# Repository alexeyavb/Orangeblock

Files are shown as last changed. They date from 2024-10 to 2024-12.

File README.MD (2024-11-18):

*Why is need:*

* WeAct studio Black pill stm32f411ceu6
* Any working pcm5102 shield configured as slave in i2s Phillips standard
* Any working pcm1808 shield configured as slave in i2s Phillips standard

**Big Steps for implementing**
+ make test board
+ write firmware fo stm32
+ write in/out audio  overlay for linux dts tree
+ write linux device driver for orange pi

**Wh implemented as demo**
+ simple i2s-i2s bridge firmware for stm32 (in+out) in 48k 24bit 256fs
+ opi worked as i2s master
+ stm32<->opi-mcu bridge as slave with internal clocking
+ stm32 i2s master reciever with internal clock and mclock/bclock output
+ stm32 i2s master transmitter with internal clock and mclock/bclock utput
+ clock dividers for 48/96/192K audio processing and internal i2s pll reconf +- 0.04% clock error

- simple stm32-i2s kernel audio device driver for use ALSA/JACKd (audio in and audio out)
- simple overlay for enabling i2s in Orange PI PC/ONE in 40pin GPIO header. Implement as 48k 24bit 256fs only without bclck change

* **20241031** Complete tracing shield
* **20241107** received factory printed boards

2024/Nov/08
* Received printed PCB
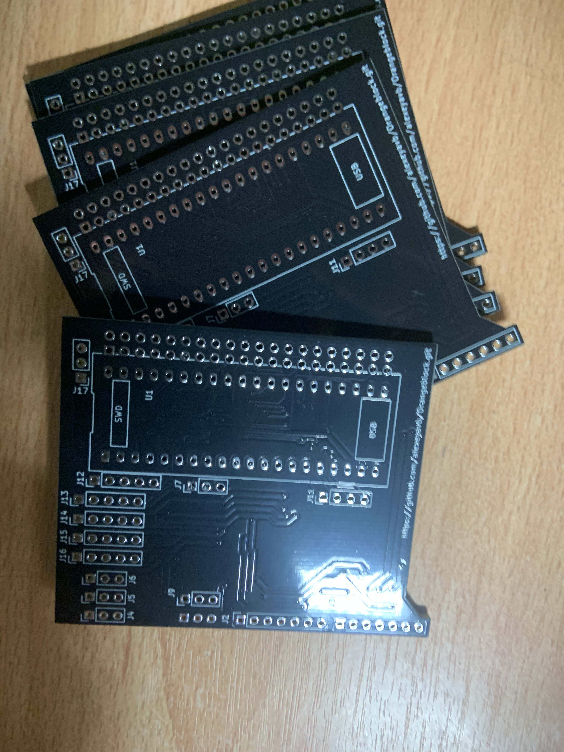
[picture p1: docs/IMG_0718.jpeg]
Printed PCB1

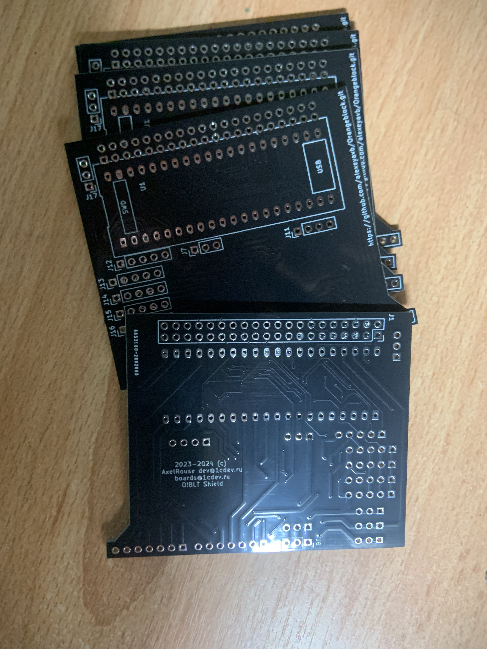
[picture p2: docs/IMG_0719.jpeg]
Printed PCB2

2024/Nov/09
* Soldered sockets anmd pins
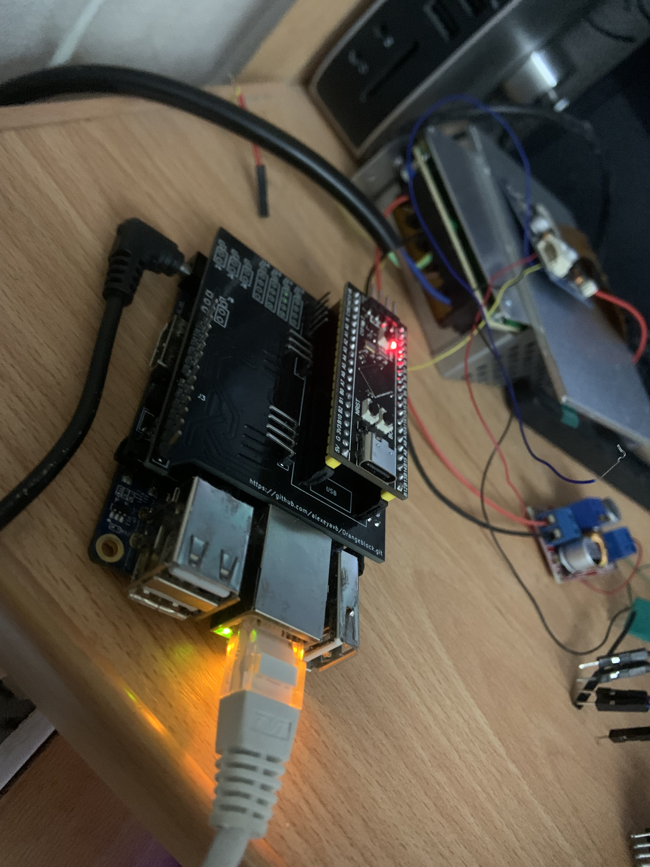
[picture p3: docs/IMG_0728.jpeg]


+ ***Process Testing with STM32 board***
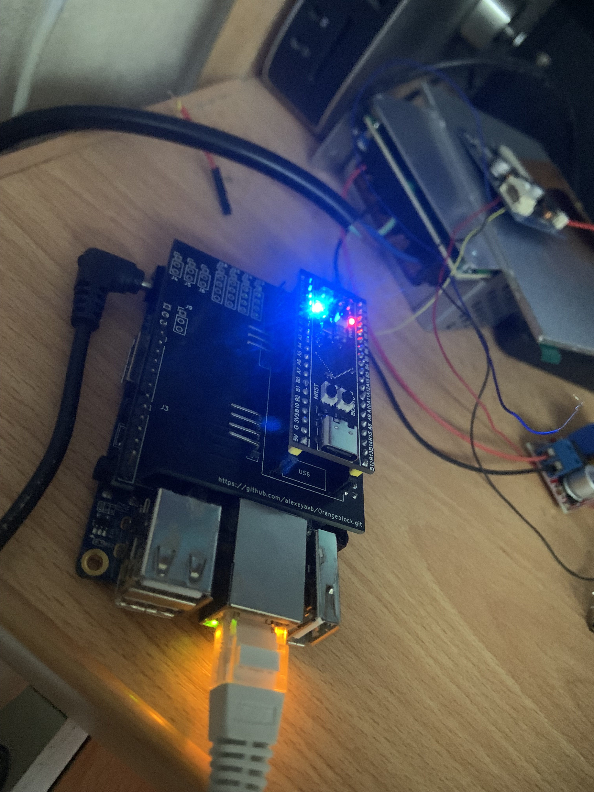
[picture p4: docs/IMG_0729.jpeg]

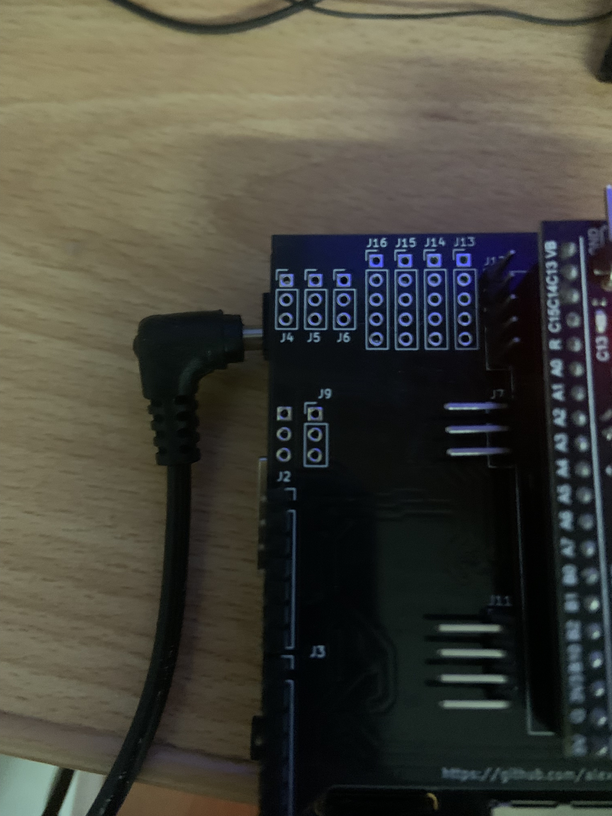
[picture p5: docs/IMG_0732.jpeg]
testing record without ADC PCB1

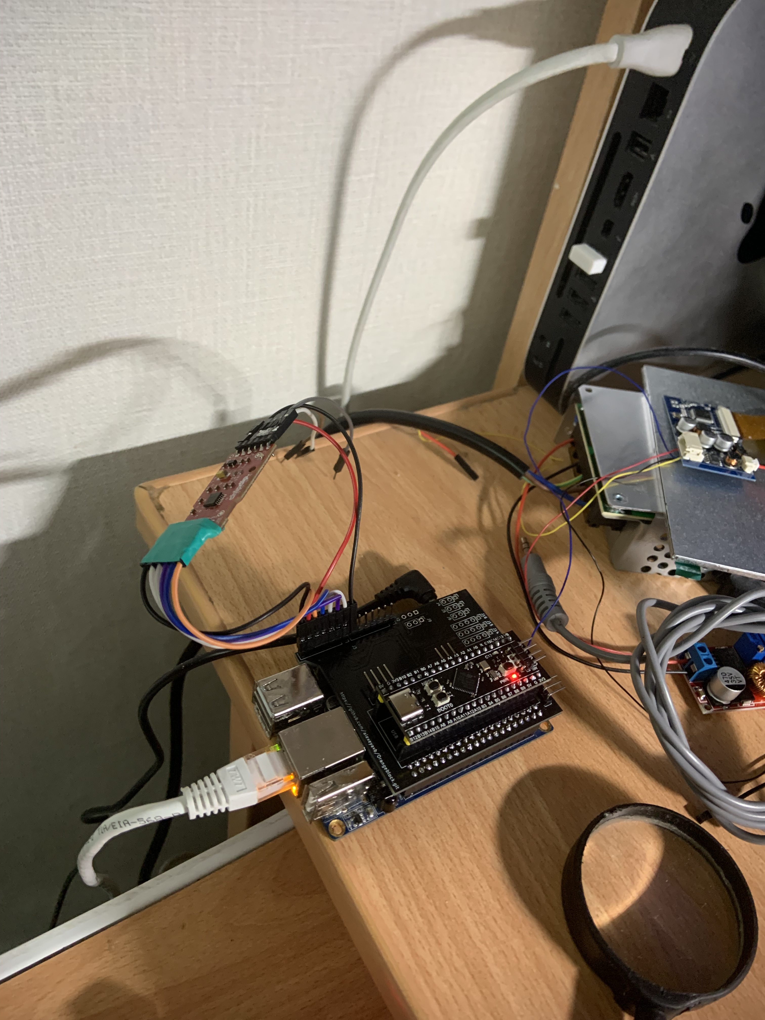
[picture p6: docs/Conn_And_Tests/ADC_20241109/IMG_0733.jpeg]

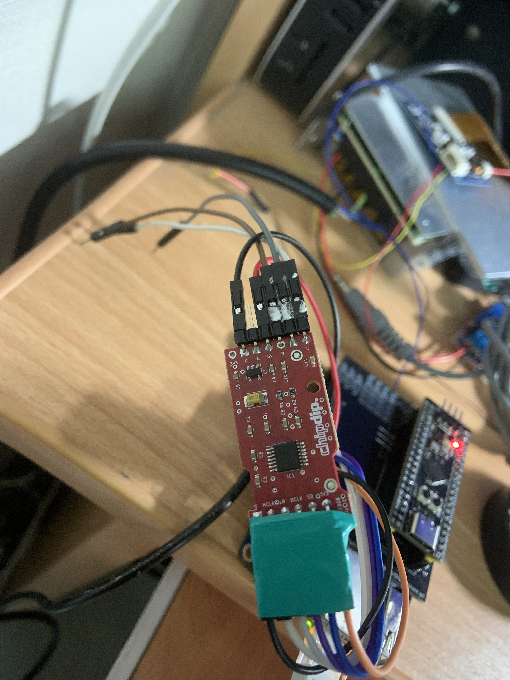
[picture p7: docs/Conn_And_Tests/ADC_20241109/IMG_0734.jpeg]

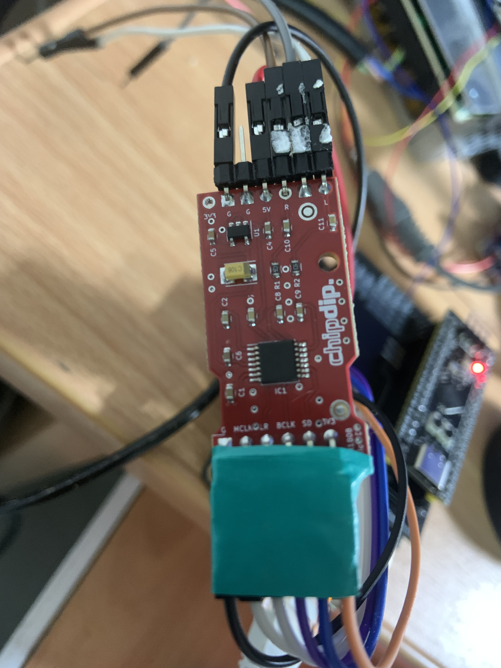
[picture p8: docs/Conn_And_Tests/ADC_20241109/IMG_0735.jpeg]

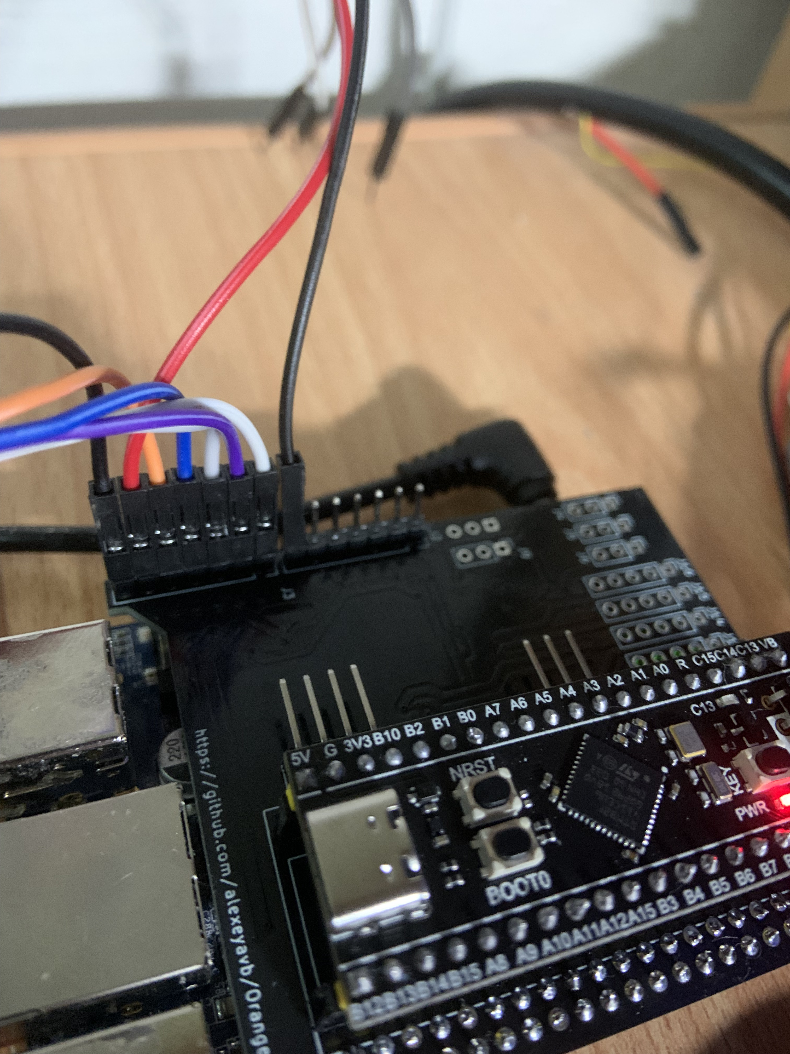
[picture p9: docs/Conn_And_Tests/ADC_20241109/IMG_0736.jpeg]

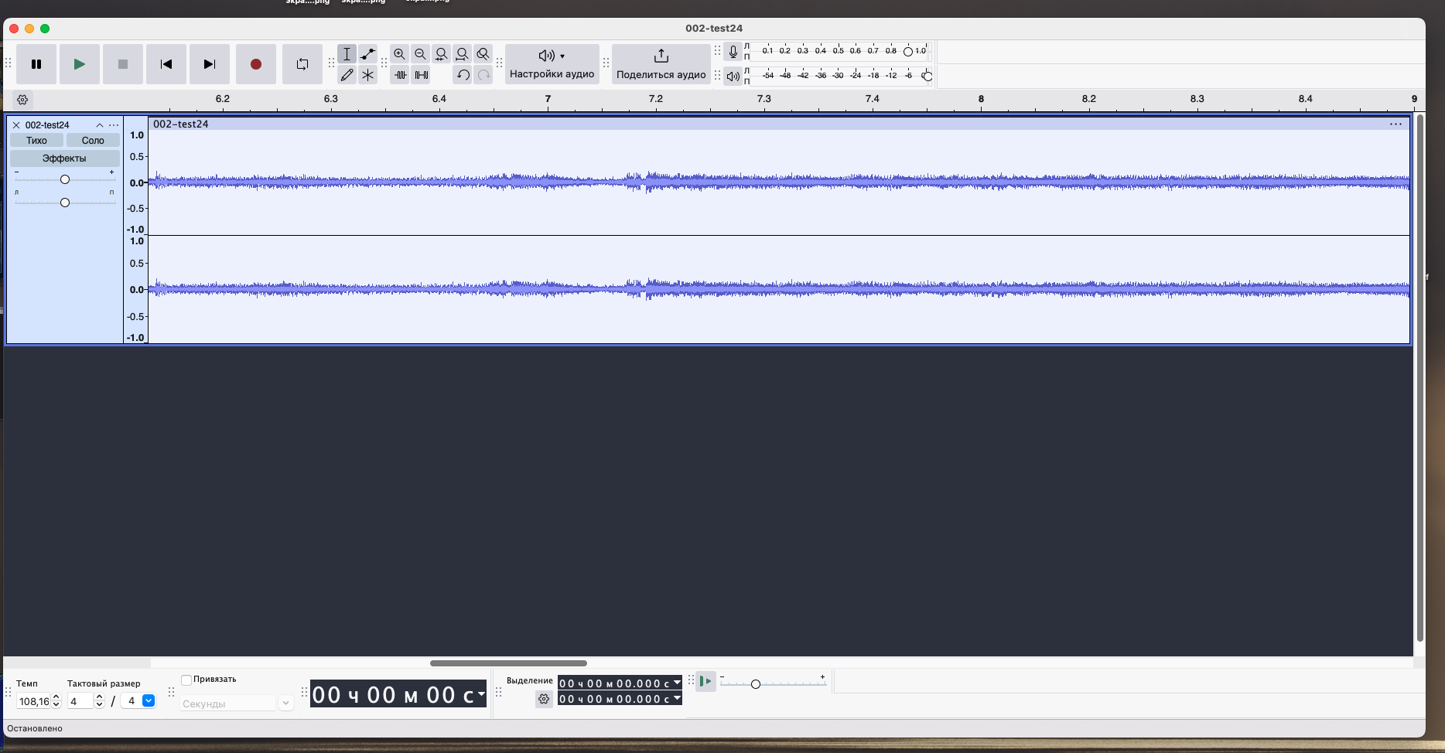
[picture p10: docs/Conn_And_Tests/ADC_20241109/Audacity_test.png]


* Testing with simple i2s hardware-factory-slave with fs autodetection configured i2s ADC 24bit pcm1808 (board from ChipDip DAC)
command: 

  ****$arecord -t raw -D "hw:1,0" -V stereo -c 2 -f S24_LE -r 32000 -d 400 -v --dump-hw-params --disable-resample ~/002-test24.dat****

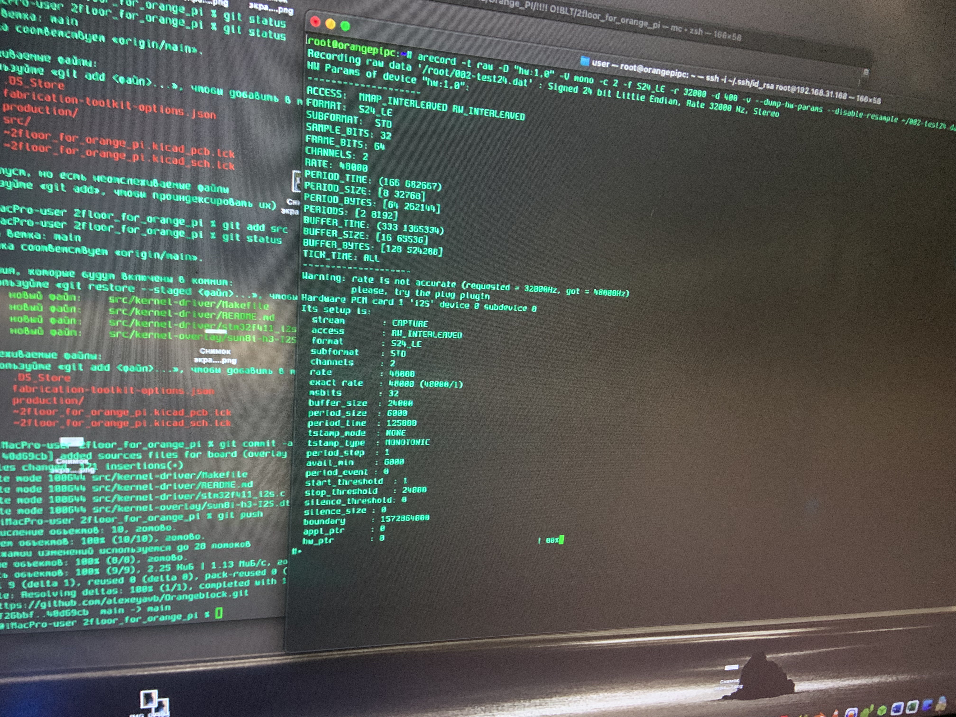
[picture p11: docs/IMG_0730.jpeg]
testing record with ADC PCB1


+ ***raw folder contained raw i2s 24bit 48k data and mp3 ()***
    +raw i2s data in folder ./docs/Conn_And_Tests/ADC_20241109/results/002-test24.dat
    +mp3 data in folder ./docs/Conn_And_Tests/ADC_20241109/results/002-test24.mp3
2024/Nov/17
* Added OPI SPI kernel overlay

+ Found issue with UART OPI positions
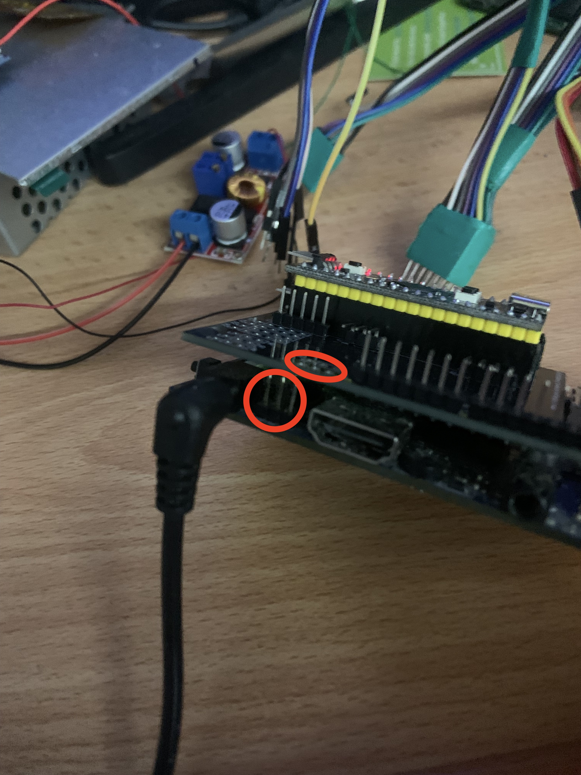
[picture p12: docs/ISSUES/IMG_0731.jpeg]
PCB1 ISSUE UART

***remarks***
There was an error in placing the socket for 3PIN UART socket from orange PI to shield. This will not interfere with functionality, but will be fixed in the next version of the board.

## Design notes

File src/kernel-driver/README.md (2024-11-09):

ENABLE FULL DUPLEX I2S ON H3 Chipset for STM32F411 board
based on ak45xx dummyy module kernel driver, intel ac97 soc driver

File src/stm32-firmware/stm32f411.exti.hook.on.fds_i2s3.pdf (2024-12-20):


25/09/2024

stm32f411.exti.hook.on Project Configuration Report

## 1. Description

### 1.1. Project

Project Name | stm32f411.exti.hook.on
Board Name | custom
Generated with: | STM32CubeMX 6.12.0
Date | 09/25/2024

### 1.2. MCU

MCU Series | STM32F4
MCU Line | STM32F411
MCU name | STM32F411CEUx
MCU Package | UFQFPN48
MCU Pin number | 48

### 1.3. Core(s) information

Core(s) | Arm Cortex-M4

## 2. Pinout Configuration

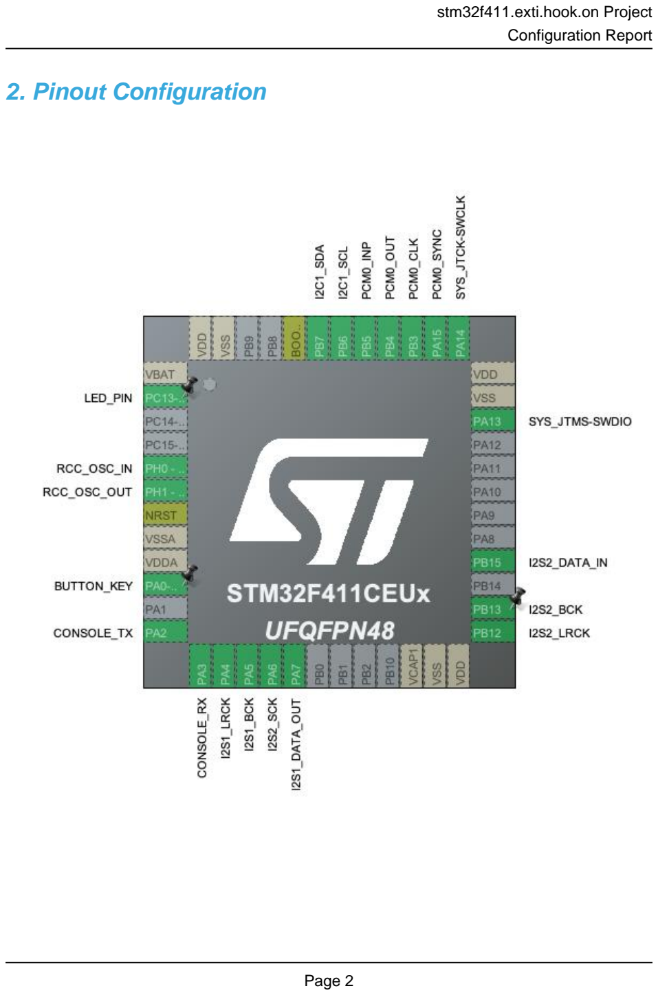
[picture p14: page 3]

## 3. Pins Configuration

Pin Number UFQFPN48 | Pin Name (function after reset) | Pin Type | Alternate Function(s) | Label
1 | VBAT | Power
2 | PC13-ANTI_TAMP * | I/O | GPIO_Output | LED_PIN
5 | PH0 - OSC_IN | I/O | RCC_OSC_IN
6 | PH1 - OSC_OUT | I/O | RCC_OSC_OUT
7 | NRST | Reset
8 | VSSA | Power
9 | VDDA | Power
10 | PA0-WKUP | I/O | GPIO_EXTI0 | BUTTON_KEY
12 | PA2 | I/O | USART2_TX | CONSOLE_TX
13 | PA3 | I/O | USART2_RX | CONSOLE_RX
14 | PA4 | I/O | I2S1_WS | I2S1_LRCK
15 | PA5 | I/O | I2S1_CK | I2S1_BCK
16 | PA6 | I/O | I2S2_MCK | I2S2_SCK
17 | PA7 | I/O | I2S1_SD | I2S1_DATA_OUT
22 | VCAP1 | Power
23 | VSS | Power
24 | VDD | Power
25 | PB12 | I/O | I2S2_WS | I2S2_LRCK
26 | PB13 | I/O | I2S2_CK | I2S2_BCK
28 | PB15 | I/O | I2S2_SD | I2S2_DATA_IN
34 | PA13 | I/O | SYS_JTMS-SWDIO
35 | VSS | Power
36 | VDD | Power
37 | PA14 | I/O | SYS_JTCK-SWCLK
38 | PA15 | I/O | I2S3_WS | PCM0_SYNC
39 | PB3 | I/O | I2S3_CK | PCM0_CLK
40 | PB4 | I/O | I2S3_ext_SD | PCM0_OUT
41 | PB5 | I/O | I2S3_SD | PCM0_INP
42 | PB6 | I/O | I2C1_SCL
43 | PB7 | I/O | I2C1_SDA
44 | BOOT0 | Boot
47 | VSS | Power
48 | VDD | Power

* The pin is affected with an I/O function

## 4. Clock Tree Configuration

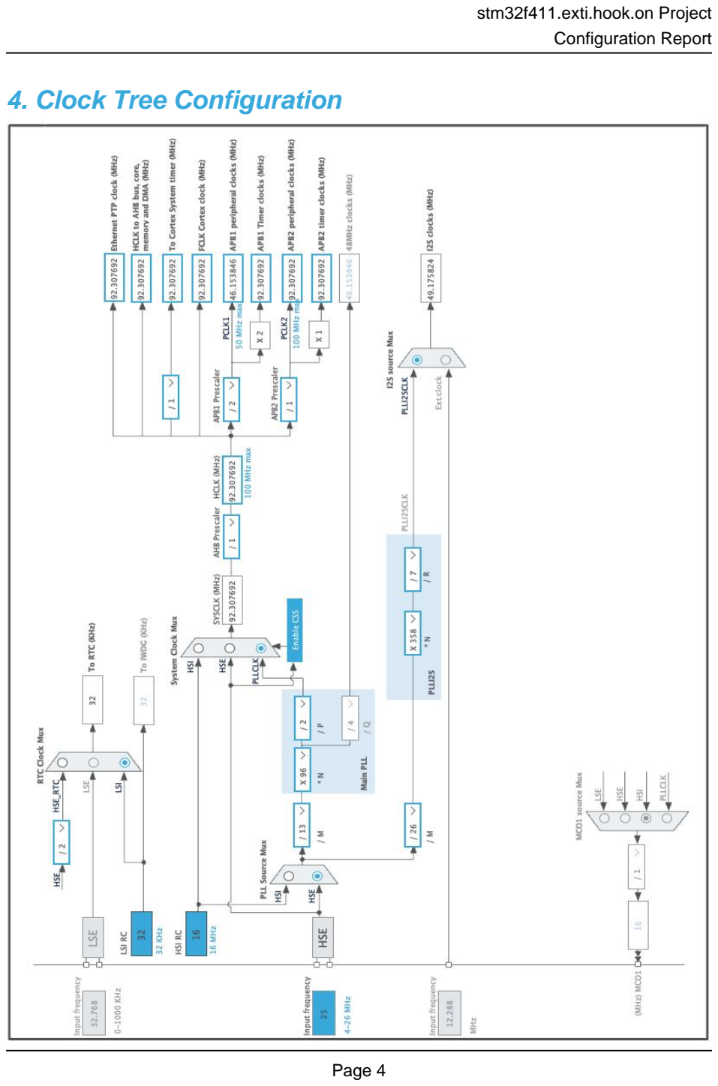
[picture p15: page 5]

## 1. Power Consumption Calculator report

### 1.1. Microcontroller Selection

Series | STM32F4
Line | STM32F411
MCU | STM32F411CEUx
Datasheet | DS10314_Rev6

### 1.2. Parameter Selection

Temperature | 25
Vdd | 1.7

### 1.3. Battery Selection

Battery | Li-SOCL2(A3400)
Capacity | 3400.0 mAh
Self Discharge | 0.08 %/month
Nominal Voltage | 3.6 V
Max Cont Current | 100.0 mA
Max Pulse Current | 200.0 mA
Cells in series | 1
Cells in parallel | 1

### 1.4. Sequence

Step | Step1 | Step2
Mode | RUN | STOP
Vdd | 1.7 | 1.7
Voltage Source | Battery | Battery
Range | Scale1-High | No Scale
Fetch Type | SRAM | n/a
CPU Frequency | 100 MHz | 0 Hz
Clock Configuration | HSE PLL | Regulator_LPLV Flash-PwrDwn
Clock Source Frequency | 4 MHz | 0 Hz
Peripherals
Additional Cons. | 0 mA | 0 mA
Average Current | 12.7 mA | 9 µA
Duration | 0.1 ms | 0.9 ms
DMIPS | 125.0 | 0.0
Ta Max | 104.31 | 105
Category | In DS Table | In DS Table

### 1.5. Results

Sequence Time | 1 ms | Average Current | 1.28 mA
Battery Life | 3 months, 19 days, 6 hours | Average DMIPS | 125.0 DMIPS

### 1.6. Chart

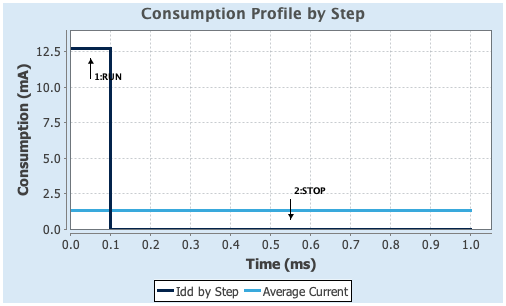
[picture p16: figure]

## 2. Software Project

### 2.1. Project Settings

Name | Value
Project Name | stm32f411.exti.hook.on.fds_i2s3
Project Folder | /Users/user/Projects/stm32f411.exti.hook.on.fds_i2s3
Toolchain / IDE | Makefile
Firmware Package Name and Version | STM32Cube FW_F4 V1.28.1
Application Structure | Advanced
Generate Under Root | No
Do not generate the main() | No
Minimum Heap Size | 0x800
Minimum Stack Size | 0x1200

### 2.2. Code Generation Settings

Name | Value
STM32Cube MCU packages and embedded software | Add necessary library files as reference in the toolchain project configuration file
Generate peripheral initialization as a pair of '.c/.h' files | Yes
Backup previously generated files when re-generating | No
Keep User Code when re-generating | Yes
Delete previously generated files when not re-generated | Yes
Set all free pins as analog (to optimize the power consumption) | No
Enable Full Assert | Yes

### 2.3. Advanced Settings - Generated Function Calls

Rank | Function Name | Peripheral Instance Name
1 | SystemClock_Config | RCC
2 | MX_GPIO_Init | GPIO
3 | MX_DMA_Init | DMA
4 | MX_USART2_UART_Init | USART2
5 | MX_I2S1_Init | I2S1
6 | MX_I2S2_Init | I2S2
7 | MX_RTC_Init | RTC
8 | MX_I2C1_Init | I2C1
9 | MX_I2S3_Init | I2S3

## 3. Peripherals and Middlewares Configuration

### 3.1. I2C1

I2C: I2C
3.1.1. Parameter Settings:

Master Features:

I2C Speed Mode | Standard Mode
I2C Clock Speed (Hz) | 100000
Slave Features:
Clock No Stretch Mode | Disabled
Primary Address Length selection | 7-bit
Dual Address Acknowledged | Disabled
Primary slave address | 16 *
General Call address detection | Disabled

### 3.2. I2S1

Mode: Half-Duplex Master
3.2.1. Parameter Settings:

Generic Parameters:

Transmission Mode | Mode Master Transmit
Communication Standard | I2S Philips
Data and Frame Format | 24 Bits Data on 32 Bits Frame *
Selected Audio Frequency | 48 KHz *
Real Audio Frequency | 48.023 KHz *
Error between Selected and Real | 0.04 % *
Clock Parameters:
Clock Source | I2S PLL Clock
Clock Polarity | Low

### 3.3. I2S2

Mode: Half-Duplex Master
mode: Master Clock Output
3.3.1. Parameter Settings:

Generic Parameters:
Transmission Mode | Mode Master Receive *
Communication Standard | I2S Philips
Data and Frame Format | 24 Bits Data on 32 Bits Frame *
Selected Audio Frequency | 48 KHz *
Real Audio Frequency | 48.023 KHz *
Error between Selected and Real | 0.04 % *
Clock Parameters:
Clock Source | I2S PLL Clock
Clock Polarity | Low

### 3.4. I2S3

Mode: Full-Duplex Slave
3.4.1. Parameter Settings:

Generic Parameters:
Transmission Mode | Mode Slave Receive *
Communication Standard | I2S Philips
Data and Frame Format | 24 Bits Data on 32 Bits Frame *
Selected Audio Frequency | 48 KHz *
Real Audio Frequency | 48.023 KHz *
Error between Selected and Real | 0.04 % *
Clock Parameters:
Clock Source | I2S PLL Clock
Clock Polarity | Low

### 3.5. RCC

High Speed Clock (HSE): Crystal/Ceramic Resonator
3.5.1. Parameter Settings:

System Parameters:

VDD voltage (V) | 3.3
Instruction Cache | Enabled
Prefetch Buffer | Enabled

Data Cache | Enabled
Flash Latency(WS) | 3 WS (4 CPU cycle)
RCC Parameters:
HSI Calibration Value | 16
TIM Prescaler Selection | Enabled *
HSE Startup Timout Value (ms) | 120 *
LSE Startup Timout Value (ms) | 5000
Power Parameters:
Power Regulator Voltage Scale | Power Regulator Voltage Scale 1

### 3.6. RTC

mode: Activate Clock Source
3.6.1. Parameter Settings:

General:

Hour Format | Hourformat 24
Asynchronous Predivider value | 127
Synchronous Predivider value | 255

### 3.7. SYS

Debug: Serial Wire
Timebase Source: SysTick

### 3.8. USART2

Mode: Asynchronous
3.8.1. Parameter Settings:

Basic Parameters:

Baud Rate | 115200
Word Length | 8 Bits (including Parity)
Parity | None
Stop Bits | 1
Advanced Parameters:
Data Direction | Receive and Transmit
Over Sampling | 8 Samples *

* User modified value

## 4. System Configuration

### 4.1. GPIO configuration

IP | Pin | Signal | GPIO mode | GPIO pull/up pull down | Max Speed | User Label
I2C1 | PB6 | I2C1_SCL | Alternate Function Open Drain | Pull-up * | Very High *
| PB7 | I2C1_SDA | Alternate Function Open Drain | Pull-up * | Very High *
I2S1 | PA4 | I2S1_WS | Alternate Function Push Pull | No pull-up and no pull-down | High * | I2S1_LRCK
| PA5 | I2S1_CK | Alternate Function Push Pull | No pull-up and no pull-down | High * | I2S1_BCK
| PA7 | I2S1_SD | Alternate Function Push Pull | No pull-up and no pull-down | High * | I2S1_DATA_OUT
I2S2 | PA6 | I2S2_MCK | Alternate Function Push Pull | No pull-up and no pull-down | High * | I2S2_SCK
| PB12 | I2S2_WS | Alternate Function Push Pull | No pull-up and no pull-down | Low | I2S2_LRCK
| PB13 | I2S2_CK | Alternate Function Push Pull | No pull-up and no pull-down | High * | I2S2_BCK
| PB15 | I2S2_SD | Alternate Function Push Pull | No pull-up and no pull-down | Medium * | I2S2_DATA_IN
I2S3 | PA15 | I2S3_WS | Alternate Function Push Pull | No pull-up and no pull-down | High * | PCM0_SYNC
| PB3 | I2S3_CK | Alternate Function Push Pull | No pull-up and no pull-down | High * | PCM0_CLK
| PB4 | I2S3_ext_SD | Alternate Function Push Pull | No pull-up and no pull-down | High * | PCM0_OUT
| PB5 | I2S3_SD | Alternate Function Push Pull | No pull-up and no pull-down | Medium * | PCM0_INP
RCC | PH0 -OSC_IN | RCC_OSC_IN | n/a | n/a | n/a
| PH1 -OSC_OUT | RCC_OSC_OUT | n/a | n/a | n/a
SYS | PA13 | SYS_JTMS-SWDIO | n/a | n/a | n/a
| PA14 | SYS_JTCK-SWCLK | n/a | n/a | n/a
USART2 | PA2 | USART2_TX | Alternate Function Push Pull | No pull-up and no pull-down | Very High * | CONSOLE_TX
| PA3 | USART2_RX | Alternate Function Push Pull | No pull-up and no pull-down | Very High * | CONSOLE_RX
GPIO | PC13-ANTI_TAMP | GPIO_Output | Output Push Pull | No pull-up and no pull-down | Low | LED_PIN
| PA0-WKUP | GPIO_EXTI0 | External Interrupt Mode with Rising edge trigger detection | Pull-down * | n/a | BUTTON_KEY

### 4.2. DMA configuration

DMA request | Stream | Direction | Priority
SPI1_TX | DMA2_Stream2 | Memory To Peripheral | Low
SPI2_RX | DMA1_Stream3 | Peripheral To Memory | Low
I2S3_EXT_TX | DMA1_Stream5 | Memory To Peripheral | Low
SPI3_RX | DMA1_Stream0 | Peripheral To Memory | Low

SPI1_TX: DMA2_Stream2 DMA request Settings:

Mode: | Circular *
Use fifo: | Disable
Peripheral Increment: | Disable
Memory Increment: | Enable *
Peripheral Data Width: | Half Word *
Memory Data Width: | Half Word *

SPI2_RX: DMA1_Stream3 DMA request Settings:

Mode: | Circular *
Use fifo: | Disable
Peripheral Increment: | Disable
Memory Increment: | Enable *
Peripheral Data Width: | Half Word *
Memory Data Width: | Half Word *

I2S3_EXT_TX: DMA1_Stream5 DMA request Settings:

Mode: | Circular *
Use fifo: | Disable
Peripheral Increment: | Disable
Memory Increment: | Enable *
Peripheral Data Width: | Half Word *
Memory Data Width: | Half Word *

SPI3_RX: DMA1_Stream0 DMA request Settings:

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

### 4.3. NVIC configuration

4.3.1. NVIC
Interrupt Table | Enable | Preenmption Priority | SubPriority
Non maskable interrupt | true | 0 | 0
Hard fault interrupt | true | 0 | 0
Memory management fault | true | 0 | 0
Pre-fetch fault, memory access fault | true | 0 | 0
Undefined instruction or illegal state | true | 0 | 0
System service call via SWI instruction | true | 2 | 3
Debug monitor | true | 2 | 3
Pendable request for system service | true | 1 | 3
System tick timer | true | 3 | 3
PVD interrupt through EXTI line 16 | true | 1 | 3
Flash global interrupt | true | 2 | 1
RCC global interrupt | true | 2 | 3
EXTI line0 interrupt | true | 0 | 0
DMA1 stream0 global interrupt | true | 0 | 0
DMA1 stream3 global interrupt | true | 0 | 0
DMA1 stream5 global interrupt | true | 0 | 0
I2C1 event interrupt | true | 0 | 0
I2C1 error interrupt | true | 0 | 0
SPI1 global interrupt | true | 3 | 2
SPI2 global interrupt | true | 3 | 2
USART2 global interrupt | true | 1 | 1
SPI3 global interrupt | true | 0 | 0
DMA2 stream2 global interrupt | true | 0 | 0
FPU global interrupt | true | 3 | 1
4.3.2. NVIC Code generation

Enabled interrupt Table Select for init
sequence ordering
| | Generate IRQ
| | handler | Call HAL handler
Non maskable interrupt | false | true | false
Hard fault interrupt | false | true | false
Memory management fault | false | true | false
Pre-fetch fault, memory access fault | false | true | false
Undefined instruction or illegal state | false | true | false
System service call via SWI instruction | false | true | false
Debug monitor | false | true | false
Pendable request for system service | false | true | false
System tick timer | false | true | true

Enabled interrupt Table | Select for init sequence ordering | Generate IRQ handler | Call HAL handler
PVD interrupt through EXTI line 16 | true | true | true
Flash global interrupt | true | true | true
RCC global interrupt | true | true | false
EXTI line0 interrupt | false | true | true
DMA1 stream0 global interrupt | false | true | true
DMA1 stream3 global interrupt | true | true | true
DMA1 stream5 global interrupt | false | true | true
I2C1 event interrupt | true | true | true
I2C1 error interrupt | true | true | true
SPI1 global interrupt | true | true | true
SPI2 global interrupt | true | true | true
USART2 global interrupt | true | true | true
SPI3 global interrupt | true | true | true
DMA2 stream2 global interrupt | true | true | true
FPU global interrupt | true | true | false

* User modified value

## 5. System Views

5.1. Category view
5.1.1. Current

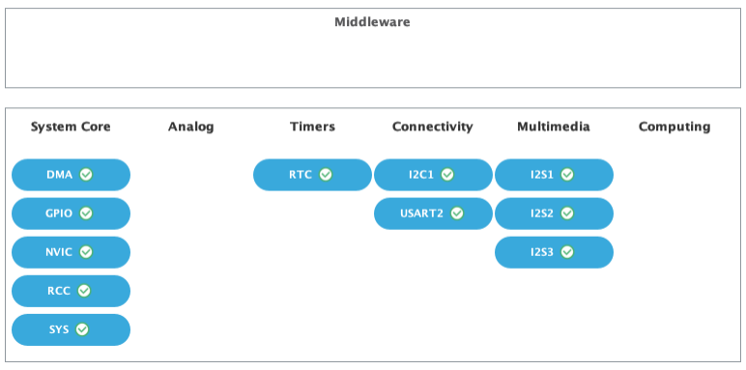
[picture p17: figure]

## 6. Docs & Resources

Type | Link
BSDL files | https://www.st.com/resource/en/bsdl_model/stm32f411_bsdl.zip
IBIS models | https://www.st.com/resource/en/ibis_model/stm32f411_ibis.zip
System View Description | https://www.st.com/resource/en/svd/stm32f4-svd.zip
Presentations | https://www.st.com/resource/en/product_presentation/stm32-stm8_embedded_software_solutions.pdf
Presentations | https://www.st.com/resource/en/product_presentation/stm32_eval-tools_portfolio.pdf
Presentations | https://www.st.com/resource/en/product_presentation/stm32_stm8_functi onal-safety-packages.pdf
Presentations | https://www.st.com/resource/en/product_presentation/stm32-stm8_software_development_tools.pdf
Presentations | https://www.st.com/resource/en/product_presentation/microcontrollers-stm32-family-overview.pdf
Presentations | https://www.st.com/resource/en/product_presentation/microcontrollers-stm32h7rs-lines-overview.pdf
Brochures | https://www.st.com/resource/en/brochure/products-and-solutions-for-plcs-and-smart-i-os.pdf
Flyers | https://www.st.com/resource/en/flyer/flstm32f4x1.pdf
Flyers | https://www.st.com/resource/en/flyer/flstm32nucleo.pdf
Flyers | https://www.st.com/resource/en/flyer/flstmcsuite.pdf
Flyers | https://www.st.com/resource/en/flyer/flstm32trust.pdf
Product Certifications | https://www.st.com/resource/en/certification_document/stm32_authentication_can.pdf
Application Notes | https://www.st.com/resource/en/application_note/an1709-emc-design-guide-for-stm8-stm32-and-legacy-mcus-stmicroelectronics.pdf
Application Notes | https://www.st.com/resource/en/application_note/an2606-stm32-microcontroller-system-memory-boot-mode-stmicroelectronics.pdf
Application Notes | https://www.st.com/resource/en/application_note/an2639-soldering-

| recommendations-and-package-information-for-leadfree-ecopack-mcus-and-mpus-stmicroelectronics.pdf
Application Notes | https://www.st.com/resource/en/application_note/an2945-stm8s-and-stm32-mcus-a-consistent-832bit-product-line-for-painless-migration-stmicroelectronics.pdf
Application Notes | https://www.st.com/resource/en/application_note/an3070-managing-the-driver-enable-signal-for-rs485-and-iolink-communications-with-the-stm32s-usart-stmicroelectronics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
Application Notes | https://www.st.com/resource/en/application_note/an3126-audio-and-waveform-generation-using-the-dac-in-stm32-products-stmicroelectronics.pdf
Application Notes | https://www.st.com/resource/en/application_note/an3154-can-protocol-used-in-the-stm32-bootloader-stmicroelectronics.pdf
Application Notes | https://www.st.com/resource/en/application_note/an3155-usart-protocol-used-in-the-stm32-bootloader-stmicroelectronics.pdf
Application Notes | https://www.st.com/resource/en/application_note/an3156-usb-dfu-protocol-used-in-the-stm32-bootloader-stmicroelectronics.pdf
Application Notes | https://www.st.com/resource/en/application_note/an3364-migration-and-compatibility-guidelines-for-stm32-microcontroller-applications-stmicroelectronics.pdf
Application Notes | https://www.st.com/resource/en/application_note/an3997-audio-playback-and-recording-using-the-stm32f4discovery-stmicroelectronics.pdf
Application Notes | https://www.st.com/resource/en/application_note/an3998-pdm-audio-software-decoding-on-stm32-microcontrollers-stmicroelectronics.pdf
Application Notes | https://www.st.com/resource/en/application_note/an4031-using-the-stm32f2-stm32f4-and-stm32f7-series-dma-controller-stmicroelectronics.pdf
Application Notes | https://www.st.com/resource/en/application_note/an4221-i2c-protocol-used-in-the-stm32-bootloader-stmicroelectronics.pdf
Application Notes | https://www.st.com/resource/en/application_note/an4229-how-to-implement-a-vocoder-solution-using-stm32-microcontrollers-stmicroelectronics.pdf
Application Notes | https://www.st.com/resource/en/application_note/an4286-spi-protocol-

| used-in-the-stm32-bootloader-stmicroelectronics.pdf
Application Notes | https://www.st.com/resource/en/application_note/an4488-getting-started-with-stm32f4xxxx-mcu-hardware-development-stmicroelectronics.pdf
Application Notes | https://www.st.com/resource/en/application_note/an4566-extending-the-dac-performance-of-stm32-microcontrollers-stmicroelectronics.pdf
Application Notes | https://www.st.com/resource/en/application_note/an4616-migrating-from-stm32f401-and-stm32f411-lines-to-stm32l4-series-and-stm32l4-series-microcontrollers-stmicroelec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
Application Notes | https://www.st.com/resource/en/application_note/an4646-peripheral-interconnections-on-stm32f401-and-stm32f411-lines-stmicroelectronics.pdf
Application Notes | https://www.st.com/resource/en/application_note/an4655-virtually-increasing-the-number-of-serial-communication-peripherals-in-stm32-applications-stmicroelectronics.p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
Application Notes | https://www.st.com/resource/en/application_note/an4739-stm32cube-firmware-examples-for-stm32f4-series-stmicroelectronics.pdf
Application Notes | https://www.st.com/resource/en/application_note/an4750-handling-of-soft-errors-in-stm32-applications-stmicroelectronics.pdf
Application Notes | https://www.st.com/resource/en/application_note/an4776-generalpurpose-timer-cookbook-for-stm32-microcontrollers-stmicroelectronics.pdf
Application Notes | https://www.st.com/resource/en/application_note/an4803-highspeed-si-simulations-using-ibis-and-boardlevel-simulations-using-hyperlynx-si-on-stm32-mcus-and-mpus-stmic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
Application Notes | https://www.st.com/resource/en/application_note/an4850-stm32-mcus-spreadspectrum-clock-generation-principles-properties-and-implementation-stmicroelectronics.pdf
Application Notes | https://www.st.com/resource/en/application_note/an4904-migration-of-microcontroller-applications-from-stm32f1-series-to-stm32f4-access-lines-stmicroelectronics.pdf
Application Notes | https://www.st.com/resource/en/application_note/an4989-stm32-microcontroller-debug-toolbox-stmicroelectronics.pdf
Application Notes | https://www.st.com/resource/en/application_note/an4995-using-an- electromyogram-technique-to-detect-muscle-activity-

| stmicroelectronics.pdf
Application Notes | https://www.st.com/resource/en/application_note/an5027-interfacing-pdm-digital-microphones-using-stm32-mcus-and-mpus-stmicroelectronics.pdf
Application Notes | https://www.st.com/resource/en/application_note/an5073-receiving-spdif-audio-stream-with-the-stm32f4f7h7-series-stmicroelectronics.pdf
Application Notes | https://www.st.com/resource/en/application_note/an4899-stm32-microcontroller-gpio-hardware-settings-and-lowpower-consumption-stmicroelectronics.pdf
Application Notes | https://www.st.com/resource/en/application_note/an5612-esd-protection-of-stm32-mcus-and-mpus-stmicroelectronics.pdf
Application Notes | https://www.st.com/resource/en/application_note/an4838-introduction-to-memory-protection-unit-management-on-stm32-mcus-stmicroelectronics.pdf
Application Notes | https://www.st.com/resource/en/application_note/an5852-migrating-from-stm32f401-stm32f410-and-stm32f411-to-stm32h503-mcus-stmicroelectronics.pdf
Application Notes | https://www.st.com/resource/en/application_note/an4879-introduction-to-usb-hardware-and-pcb-guidelines-using-stm32-mcus-stmicroelectronics.pdf
Application Notes | https://www.st.com/resource/en/application_note/an5225-introduction-to-usb-typec-power-delivery-for-stm32-mcus-and-mpus-stmicroelectronics.pdf
Application Notes | https://www.st.com/resource/en/application_note/an2834-how-to-optimize-the-adc-accuracy-in-the-stm32-mcus-stmicroelectronics.pdf
Application Notes | https://www.st.com/resource/en/application_note/an5537-how-to-use-adc-oversampling-techniques-to-improve-signaltonoise-ratio-on-stm32-mcus-stmicroelectronics.pdf
Application Notes | https://www.st.com/resource/en/application_note/an5036-guidelines-for-thermal-management-on-stm32-applications-stmicroelectronics.pdf
Application Notes | https://www.st.com/resource/en/application_note/an4230-introduction-to-random-number-generation-validation-using-the-nist-statistical-test-suite-for-stm32-mcus-and-m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
Application Notes | https://www.st.com/resource/en/application_note/an2867-guidelines-for-

| oscillator-design-on-stm8afals-and-stm32-mcusmpus-stmicroelectronics.pdf
Application Notes | https://www.st.com/resource/en/application_note/an4013-introduction-to-timers-for-stm32-mcus-stmicroelectronics.pdf
Application Notes | https://www.st.com/resource/en/application_note/an4277-how-to-use-pwm-shutdown-for-motor-control-and-digital-power-conversion-on-stm32-mcus-stmicroelectronics.pdf
Application Notes | https://www.st.com/resource/en/application_note/an4759-introduction-to-using-the-hardware-realtime-clock-rtc-and-the-tamper-management-unit-tamp-with-stm32-mcus-stmi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
Application Notes | https://www.st.com/resource/en/application_note/an4908-getting-started-with-usart-automatic-baud-rater-detection-for-stm32-mcus-stmicroelectronics.pdf
Application Notes | https://www.st.com/resource/en/application_note/an5156-introduction-to-security-for-stm32-mcus-stmicroelectronics.pdf
Application Notes | https://www.st.com/resource/en/application_note/an5543-guidelines-for-enhanced-spi-communication-on-stm32-mcus-and-mpus-stmicroelectronics.pdf
Application Notes for related Tools & Software | https://www.st.com/resource/en/application_note/an1202_freertos_guide-freertos-guide-stmicroelectronics.pdf
Application Notes for related Tools & Software | https://www.st.com/resource/en/application_note/an1602_semihosting_in_truestudio-how-to-do-semihosting-in-truestudio-stmicroelectronics.pdf
Application Notes for related Tools & Software | https://www.st.com/resource/en/application_note/an1801_stm32cubeprogrammer_in_truestudio-installing-stm32cubeprogrammer-in-truestudio-stmicroelectronics.pdf
Application Notes for related Tools & Software | https://www.st.com/resource/en/application_note/atollic_editing_keyboard_shortcuts-atollic-editing-keyboard-shortcuts-stmicroelectronics.pdf
Application Notes for related Tools & Software | https://www.st.com/resource/en/application_note/iar_to_atollic_truestudio_migration_guide-truestudio-for-arm-migration-guide-iar-embedded-workbench-to-truestudio-stm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
Application Notes | https://www.st.com/resource/en/application_note/stm32cubemx_installatio

for related Tools & Software | n_in_truestudio-stm32cubemx-installation-in-truestudio-stmicroelectronics.pdf
Application Notes for related Tools & Software | https://www.st.com/resource/en/application_note/an2656-stm32f10xxx-lcd-glass-driver-firmware-stmicroelectronics.pdf
Application Notes for related Tools & Software | https://www.st.com/resource/en/application_note/an2790-tft-lcd-interfacing-with-the-highdensity-stm32f10xxx-fsmc-stmicroelectronics.pdf
Application Notes for related Tools & Software | https://www.st.com/resource/en/application_note/an3078-stm32-inapplication-programming-over-the-ic-bus-stmicroelectronics.pdf
Application Notes for related Tools & Software | https://www.st.com/resource/en/application_note/an3116-stm32s-adc-modes-and-their-applications-stmicroelectronics.pdf
Application Notes for related Tools & Software | https://www.st.com/resource/en/application_note/an3174-implementing-receivers-for-infrared-remote-control-protocols-using-stm32f10xxx-microcontrollers-stmicroelectro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
Application Notes for related Tools & Software | https://www.st.com/resource/en/application_note/an3241-qvga-tftlcd-direct-drive-using-the-stm32f10xx-fsmc-peripheral-stmicroelectronics.pdf
Application Notes for related Tools & Software | https://www.st.com/resource/en/application_note/an3307-guidelines-for-obtaining-iec-60335-class-b-certification-for-any-stm32-application-stmicroelectronics.pdf
Application Notes for related Tools & Software | https://www.st.com/resource/en/application_note/an3965-stm32f40xstm32f41x-inapplication-programming-using-the-usart-stmicroelectronics.pdf
Application Notes for related Tools & Software | https://www.st.com/resource/en/application_note/an3969-eeprom-emulation-in-stm32f40xstm32f41x-microcontrollers-stmicroelectronics.pdf
Application Notes for related Tools & Software | https://www.st.com/resource/en/application_note/an4044-floating-point-unit-demonstration-on-stm32-microcontrollers-stmicroelectronics.pdf

Application Notes
for related Tools

https://www.st.com/resource/en/application_note/an4323-getting-startedwith-stemwin-library-stmicroelectronics.pdf

& Software
Application Notes for related Tools & Software | https://www.st.com/resource/en/application_note/an4365-using-stm32f4-mcu-power-modes-with-best-dynamic-efficiency-stmicroelectronics.pdf
Application Notes for related Tools & Software | https://www.st.com/resource/en/application_note/an4435-guidelines-for-obtaining-ulcsaiec-607301603351-class-b-certification-in-any-stm32-application-stmicroelectroni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
Application Notes for related Tools & Software | https://www.st.com/resource/en/application_note/an4457-implementing-an-emulated-uart-on-stm32f4-microcontrollers-stmicroelectronics.pdf
Application Notes for related Tools & Software | https://www.st.com/resource/en/application_note/an4499-stm32--nrf51822-bluetooth-low-energy-system-solution-stmicroelectronics.pdf
Application Notes for related Tools & Software | https://www.st.com/resource/en/application_note/an4515-using-batch-acquisition-mode-bam-to-maximize-power-efficiency-on-stm32f410-stm32f411-stm32f412-stm32f413-micro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
Application Notes for related Tools & Software | https://www.st.com/resource/en/application_note/an4657-stm32-inapplication-programming-iap-using-the-usart-stmicroelectronics.pdf
Application Notes for related Tools & Software | https://www.st.com/resource/en/application_note/an4666-parallel-synchronous-transmission-using-gpio-and-dma-stmicroelectronics.pdf
Application Notes for related Tools & Software | https://www.st.com/resource/en/application_note/an4678-full-duplex-spi-emulation-for-stm32f4-microcontrollers-stmicroelectronics.pdf
Application Notes for related Tools & Software | https://www.st.com/resource/en/application_note/an4701-proprietary-code-readout-protection-on-microcontrollers-of-the-stm32f4-series-stmicroelectronics.pdf
Application Notes for related Tools & Software | https://www.st.com/resource/en/application_note/an4739-stm32cube-firmware-examples-for-stm32f4-series-stmicroelectronics.pdf

Application Notes
for related Tools

https://www.st.com/resource/en/application_note/an4758-proprietarycode-readout-protection-on-stm32l4-stm32l4-stm32g4-and-stm32wb-

& Software | series-mcus-stmicroelectronics.pdf
Application Notes for related Tools & Software | https://www.st.com/resource/en/application_note/an4841-digital-signal-processing-for-stm32-microcontrollers-using-cmsis-stmicroelectronics.pdf
Application Notes for related Tools & Software | https://www.st.com/resource/en/application_note/an4968-proprietary-code-read-out-protection-pcrop-on-stm32f72xxx-and-stm32f73xxx-microcontrollers-stmicroelectronics.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
Application Notes for related Tools & Software | https://www.st.com/resource/en/application_note/an5056-integration-guide-for-the-xcubesbsfu-stm32cube-expansion-package-stmicroelectronics.pdf
Application Notes for related Tools & Software | https://www.st.com/resource/en/application_note/an5360-getting-started-with-projects-based-on-the-stm32mp1-series-in-stm32cubeide-stmicroelectronics.pdf
Application Notes for related Tools & Software | https://www.st.com/resource/en/application_note/an5361-getting-started-with-projects-based-on-dualcore-stm32h7-microcontrollers-in-stm32cubeide-stmicroelectronics.pd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
Application Notes for related Tools & Software | https://www.st.com/resource/en/application_note/an5394-getting-started-with-projects-based-on-the-stm32l5-series-in-stm32cubeide-stmicroelectronics.pdf
Application Notes for related Tools & Software | https://www.st.com/resource/en/application_note/an5418-how-to-build-a-simple-usbpd-sink-application-with-stm32cubemx-stmicroelectronics.pdf
Application Notes for related Tools & Software | https://www.st.com/resource/en/application_note/an5426-migrating-graphics-middleware-projects-from-stm32cubemx-540-to-stm32cubemx-550-stmicroelectronics.pdf
Application Notes for related Tools & Software | https://www.st.com/resource/en/application_note/an5464-position-control-of-a-threephase-permanent-magnet-motor-using-xcubemcsdk-or-xcubemcsdkful-stmicroelectronics.p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
Application Notes for related Tools & Software | https://www.st.com/resource/en/application_note/an5564-getting-started-with-projects-based-on-dualcore-stm32wl-microcontrollers-in-stm32cubeide-stmicroelectronics.pd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
Application Notes for related Tools & Software | https://www.st.com/resource/en/application_note/an5698-adapting-the-xcubestl-functional-safety-package-for-stm32-iec-61508-compliant-to-other-safety-standards-stmicr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

Application Notes for related Tools & Software | https://www.st.com/resource/en/application_note/an5731-stm32cubemx-and-stm32cubeide-threadsafe-solution-stmicroelectronics.pdf
Application Notes for related Tools & Software | https://www.st.com/resource/en/application_note/an4502-stm32-smbuspmbus-expansion-package-for-stm32cube-stmicroelectronics.pdf
Application Notes for related Tools & Software | https://www.st.com/resource/en/application_note/an5952-how-to-use-cmake-in-stm32cubeide-stmicroelectronics.pdf
Application Notes for related Tools & Software | https://www.st.com/resource/en/application_note/an5054-how-to-perform-secure-programming-using-stm32cubeprogrammer-stmicroelectronics.pdf
Design Notes & Tips | https://www.st.com/resource/en/design_tip/dt0088-fir-filter-design-by-sampling-windowing-and-modulating-the-sinc-function-stmicroelectronics.pdf
Design Notes & Tips | https://www.st.com/resource/en/design_tip/dt0089-the-goertzel-algorithm-to-compute-individual-terms-of-the-discrete-fourier-transform-dft-stmicroelectronics.pdf
Design Notes & Tips | https://www.st.com/resource/en/design_tip/dt0091-lattice-wave-digital-filter-design-and-automatic-c-code-generation-stmicroelectronics.pdf
Design Notes & Tips | https://www.st.com/resource/en/design_tip/dt0092-lattice-wave-digital-filter-test-and-performance-verification-stmicroelectronics.pdf
Device Option Lists | https://www.st.com/resource/en/device_option_list/opl_stm32f411_512k.zi p
Errata Sheets | https://www.st.com/resource/en/errata_sheet/es0287-stm32f411xcxe-device-errata-stmicroelectronics.pdf
Datasheet | https://www.st.com/resource/en/datasheet/dm00115249.pdf
Programming Manuals | https://www.st.com/resource/en/programming_manual/pm0214-stm32-cortexm4-mcus-and-mpus-programming-manual-stmicroelectronics.pdf
Reference Manuals | https://www.st.com/resource/en/reference_manual/rm0383-stm32f411xce-advanced-armbased-32bit-mcus-stmicroelectronics.pdf

Technical Notes
& Articles

https://www.st.com/resource/en/technical_note/tn0516-overview-of-thestm32f0xf100xxf103xx-and-stm32f2xxf30xf4xx-mcus-pmsm-singledual-

| foc-sdk-v40-stmicroelectronics.pdf
Technical Notes & Articles | https://www.st.com/resource/en/technical_note/tn1163-description-of-wlcsp-for-microcontrollers-and-recommendations-for-its-use-stmicroelectronics.pdf
Technical Notes & Articles | https://www.st.com/resource/en/technical_note/tn1204-tape-and-reel-shipping-media-for-stm32-microcontrollers-in-bga-packages-stmicroelectronics.pdf
Technical Notes & Articles | https://www.st.com/resource/en/technical_note/tn1205-tape-and-reel-shipping-media-for-stm8-and-stm32-microcontrollers-in-fpn-packages-stmicroelectronics.pdf
Technical Notes & Articles | https://www.st.com/resource/en/technical_note/tn1206-tape-and-reel-shipping-media-for-stm8-and-stm32-microcontrollers-in-qfp-packages-stmicroelectronics.pdf
Technical Notes & Articles | https://www.st.com/resource/en/technical_note/tn1207-tape-and-reel-shipping-media-for-stm8-and-stm32-microcontrollers-in-so-packages-stmicroelectronics.pdf
Technical Notes & Articles | https://www.st.com/resource/en/technical_note/tn1208-tape-and-reel-shipping-media-for-stm8-and-stm32-microcontrollers-in-tssop-and-ssop-packages-stmicroelectronics.p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
Technical Notes & Articles | https://www.st.com/resource/en/technical_note/tn1433-reference-device-marking-schematics-for-stm32-microcontrollers-and-microprocessors-stmicroelectronics.pdf
Technical Notes & Articles | https://www.st.com/resource/en/technical_note/tn1489-security-bulletin-tn1489stpsirt-physical-attacks-on-stm32-and-stm32cube-firmware-stmicroelectronics.pdf

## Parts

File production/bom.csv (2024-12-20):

Designator | Footprint | Quantity | Value | LCSC Part #
J1 | PinSocket_2x20_P2.54mm_Vertical | 1 | Orange_PI_PC_ONE_40Pin_Header
J11 | PinHeader_1x04_P2.54mm_Vertical | 1 | OPI SPI0 Header
J12 | PinHeader_1x05_P2.54mm_Vertical | 1 | ST7735 Header
J13, J14, J15, J16 | PinHeader_1x05_P2.54mm_Vertical | 4 | SPI5 Header
J17 | PinHeader_1x03_P2.54mm_Vertical | 1 | STM32 GPIO Header
J2 | PinSocket_1x07_P2.54mm_Vertical | 1 | I2S1 DAC Socket
J3 | PinSocket_1x07_P2.54mm_Vertical | 1 | I2S2 ADC Socket
J4 | PinHeader_1x03_P2.54mm_Vertical | 1 | +3V3 Header
J5 | PinHeader_1x03_P2.54mm_Vertical | 1 | +5V Header
J6 | PinHeader_1x03_P2.54mm_Vertical | 1 | GND Header
J7 | PinHeader_1x03_P2.54mm_Vertical | 1 | STM32 DEBUG Header
J8 | PinSocket_1x03_P2.54mm_Vertical | 1 | OPI Conn Debug Socket
J9 | PinHeader_1x03_P2.54mm_Vertical | 1 | OPI Conn Debug Header
U1 | STM32_WeActSt_BlackPill | 1 | ~

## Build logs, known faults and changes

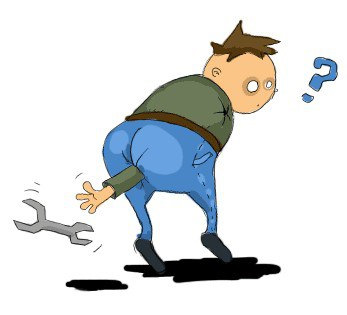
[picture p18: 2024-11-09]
docs/ISSUES/10__aysx8usi6RUSdrJRNcI6uHo-480.jpg

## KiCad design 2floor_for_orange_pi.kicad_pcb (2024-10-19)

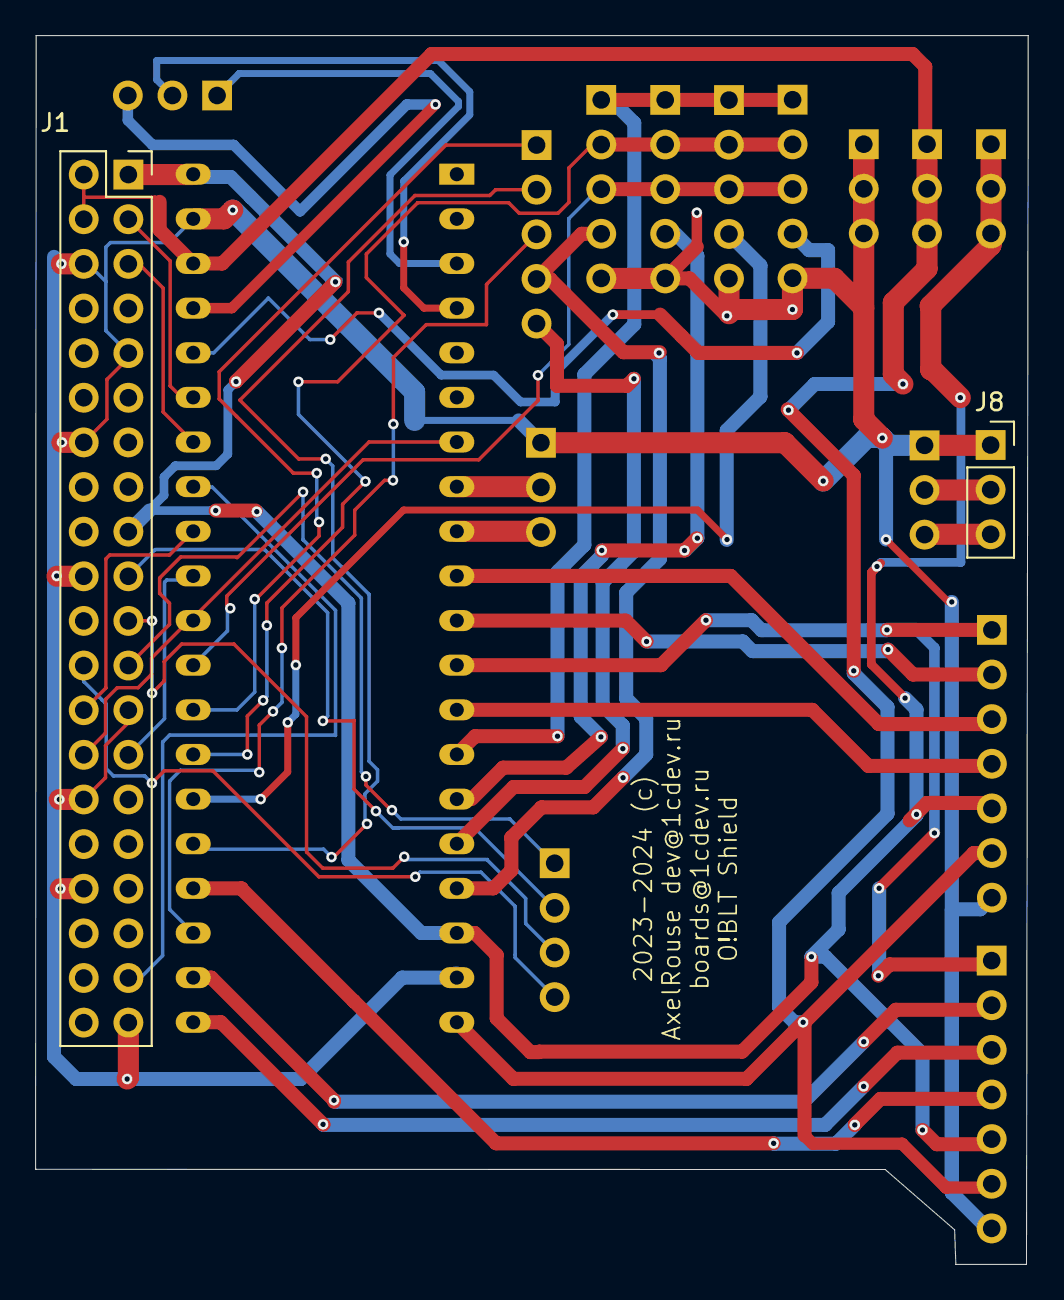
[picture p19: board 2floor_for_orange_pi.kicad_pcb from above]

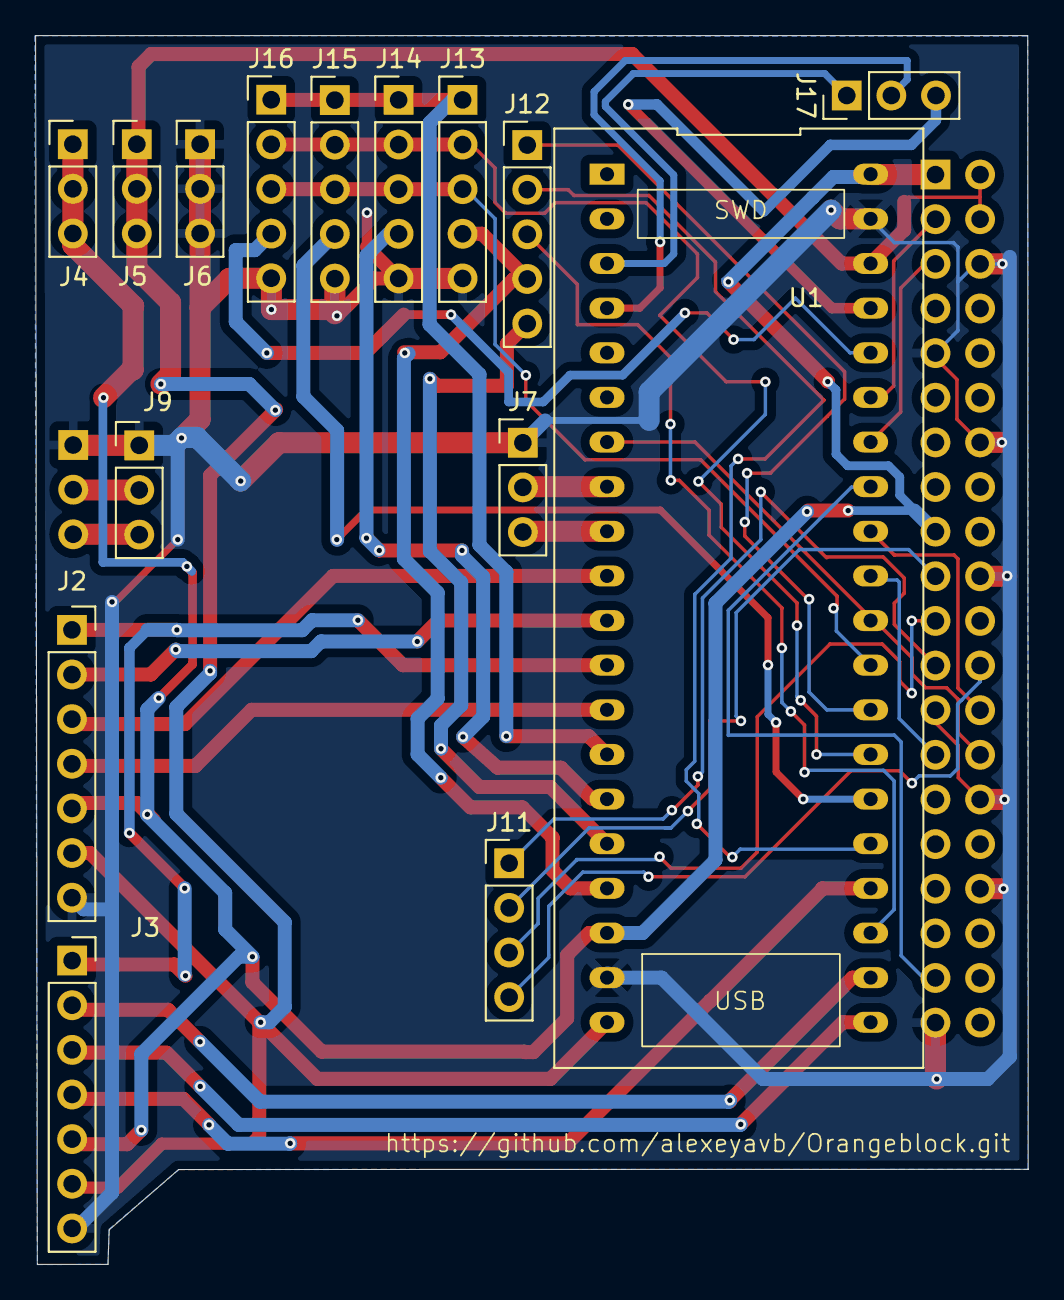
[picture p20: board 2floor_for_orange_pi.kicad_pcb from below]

Board: 2 copper layers, 56.5 x 69.9 mm, 17 parts (15 on the bottom side), 36 nets.

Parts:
J1: Orange_PI_PC_ONE_40Pin_Header; PinSocket_2x20_P2.54mm_Vertical
J2: I2S1 DAC Socket; PinSocket_1x07_P2.54mm_Vertical
J3: I2S2 ADC Socket; PinSocket_1x07_P2.54mm_Vertical
J4: +3V3 Header; PinHeader_1x03_P2.54mm_Vertical
J5: +5V Header; PinHeader_1x03_P2.54mm_Vertical
J6: GND Header; PinHeader_1x03_P2.54mm_Vertical
J7: STM32 DEBUG Header; PinHeader_1x03_P2.54mm_Vertical
J8: OPI Conn Debug Socket; PinSocket_1x03_P2.54mm_Vertical
J9: OPI Conn Debug Header; PinHeader_1x03_P2.54mm_Vertical
J11: OPI SPI0 Header; PinHeader_1x04_P2.54mm_Vertical
J12: ST7735 Header; PinHeader_1x05_P2.54mm_Vertical
J13, J14, J15, J16: SPI5 Header; PinHeader_1x05_P2.54mm_Vertical
J17: STM32 GPIO Header; PinHeader_1x03_P2.54mm_Vertical
U1: STM32_WeActSt_BlackPill

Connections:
+3V3: J1.1 (3V3), J1.17 (3V3), J2.5, J3.5, J4.1, J4.2, J4.3, U1.18 (3V3), U1.40 (3V3)
+5V: J1.2 (5V), J1.4 (5V), J2.6, J3.6, J5.1, J5.2, J5.3, U1.20 (5v), U1.38 (5v)
/I2S1_BCK: J2.2, U1.11 (A5)
/I2S1_Data_Out: J2.4, U1.13 (A7)
/I2S1_LRCK: J2.3, U1.10 (A4)
/I2S2_BCK: J3.2, U1.22 (B13)
/I2S2_DATA_IN: J3.4, U1.24 (B15)
/I2S2_LRCK: J3.3, U1.21 (B12)
/I2S2_SCK: J2.1, J3.1, U1.12 (A6)
/PCM0_CLCK: J1.27 ((PA19)), U1.31 (B3)
/PCM0_DIN: J1.26 ((PA21)), U1.32 (B4)
/PCM0_DOUT: J1.37 ((PA20)/PA20), U1.33 (B5)
/PCM0_SYNC: J1.28 ((PA18)), U1.7 (A1), U1.30 (A15)
/SPI5_CS1: J14.4, U1.15 (B1)
/SPI5_CS2: J15.4, U1.26 (A9)
/SPI5_CS3: J16.4, U1.36 (B8)
/SPI5_MISO: J13.3, J14.3, J15.3, J16.3, U1.29 (A12)
/SPI5_MOSI: J13.2, J14.2, J15.2, J16.2, U1.27 (A10)
/SPI5_SCK: J13.1, J14.1, J15.1, J16.1, U1.14 (B0)
/ST7735_BL: J12.2, U1.25 (A8)
/ST7735_CS: J12.4, J13.4, U1.17 (B10)
/ST7735_DC: J12.3, U1.23 (B14)
/ST7735_RES: J12.5, U1.16 (B2)
/TIM1_PWM_OUTPUT: J12.1, U1.28 (A11)
/UART_RX: J7.3, U1.9 (A3)
/UART_TX: J7.2, U1.8 (A2)
GND: J1.6 (GND), J1.9 (GND), J1.14 (GND), J1.20 (GND), J1.25 (GND), J1.30 (GND), J1.34 (GND), J1.39 (GND), J2.7, J3.7, J6.1, J6.2, J6.3, J7.1, J8.1, J9.1, J13.5, J14.5, J15.5, J16.5, U1.19 (G), U1.39 (G)
unnamed: J1.5 ((PA11)/TWI0_SCK), U1.34 (B6)
unnamed: J1.3 ((PA12)/TWI0_SDA), U1.35 (B7)
unnamed: J1.19 ((PC0)/SPI0_MOSI), J11.2
unnamed: J1.21 ((PC1)/SPI0_MISO), J11.3
unnamed: J1.23 ((PC2)/SPI0_SCK), J11.1
unnamed: J1.24 ((PC3}/SPI0_CS), J11.4
unnamed: J17.3, U1.37 (B9)
unnamed: J17.1, U1.3 (C14)
unnamed: J17.2, U1.4 (C15)

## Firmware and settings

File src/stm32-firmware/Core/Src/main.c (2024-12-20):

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
/* Includes ------------------------------------------------------------------*/
#include "main.h"
#include "dma.h"
#include "i2c.h"
#include "i2s.h"
#include "rtc.h"
#include "usart.h"
#include "gpio.h"


/* USER CODE BEGIN PV */
static uint8_t led_on = 0x00;

#define LR_COUNT_START 16
static uint16_t current_lr_counter = 0;
static uint8_t DMA_Started = 0x00;

#define SEND_BUFF_SZ 8
static uint16_t send_buff[SEND_BUFF_SZ] = {0};
static uint16_t rcv_buff[SEND_BUFF_SZ] = {0};
static uint16_t adc_buff[SEND_BUFF_SZ] = {0};

// #define TRANSMIT_TIMEOUT 1000
#define TRANSMIT_TIMEOUT 1200
static uint16_t tm_timeout = 0;


static uint8_t adc_dma_started = 0x00;
/* USER CODE END PV */

void SystemClock_Config(void);
void PeriphCommonClock_Config(void);
static void MX_NVIC_Init(void);
/* USER CODE BEGIN 0 */
static inline void i2s3_full_stop(void){
    GPIO_InitTypeDef GPIO_InitStruct = {0};

    GPIO_InitStruct.Pin = PCM0_CLK_Pin;
    GPIO_InitStruct.Mode = GPIO_MODE_INPUT;
    GPIO_InitStruct.Pull = GPIO_NOPULL;
    GPIO_InitStruct.Speed = GPIO_SPEED_FREQ_LOW;
    // GPIO_InitStruct.Alternate = ;
    HAL_GPIO_Init(PCM0_CLK_GPIO_Port, &GPIO_InitStruct);
}

// static inline void i2s2_full_stop(void){
//     GPIO_InitTypeDef GPIO_InitStruct = {0};

//     GPIO_InitStruct.Pin = I2S1_LRCK_Pin|I2S1_BCK_Pin|I2S1_DATA_OUT_Pin;
//     GPIO_InitStruct.Mode = GPIO_MODE_INPUT;
//     GPIO_InitStruct.Pull = GPIO_NOPULL;
//     GPIO_InitStruct.Speed = GPIO_SPEED_FREQ_LOW;
//     // GPIO_InitStruct.Alternate = GPIO_AF5_SPI1;
//     HAL_GPIO_Init(GPIOA, &GPIO_InitStruct);
// }
/* USER CODE END 0 */

/**
  * @brief  The application entry point.
  * @retval int
  */
int main(void)
{

  /* MCU Configuration--------------------------------------------------------*/

  /* Reset of all peripherals, Initializes the Flash interface and the Systick. */
  HAL_Init();

  /* Configure the system clock */
  SystemClock_Config();

  /* Configure the peripherals common clocks */
  PeriphCommonClock_Config();

  /* Initialize all configured peripherals */
  MX_GPIO_Init();
  MX_DMA_Init();
  MX_USART2_UART_Init();
  MX_RTC_Init();
  MX_I2C1_Init();
  MX_I2S1_Init();
  // MX_I2S2_Init();
  // MX_I2S3_Init();

  /* Initialize interrupts */
  MX_NVIC_Init();
  /* USER CODE BEGIN 2 */
  HAL_GPIO_WritePin(LED_PIN_GPIO_Port, LED_PIN_Pin, GPIO_PIN_SET);
  

  /* USER CODE END 2 */
  

  /* Infinite loop */
  /* USER CODE BEGIN WHILE */
  while (1)
  {
    /* USER CODE END WHILE */    
      tm_timeout = DMA_Started ? tm_timeout+1 : 0;
      if(tm_timeout >= TRANSMIT_TIMEOUT){
        i2s3_full_stop();
        HAL_I2S_DeInit(&hi2s3);
        // HAL_Delay(5);
        MX_I2S3_Init();
        DMA_Started = 0x0;
        tm_timeout = 0;
      }

      if(DMA_Started && !adc_dma_started){        
        adc_dma_started = 0x1;
      }

      if(!DMA_Started && adc_dma_started){        
        HAL_I2S_DeInit(&hi2s2);
        // HAL_Delay(5);
        MX_I2S2_Init();
        // memset((uint8_t*)&adc_buff[0], 0x00, sizeof(adc_buff[0])*SEND_BUFF_SZ);

        if(led_on){
          HAL_GPIO_WritePin(LED_PIN_GPIO_Port, LED_PIN_Pin, GPIO_PIN_SET);
          led_on = 0x0;
        }

        adc_dma_started = 0x0;
      }

    /* USER CODE BEGIN 3 */
  }
  /* USER CODE END 3 */
}

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
/* USER CODE BEGIN 4 */

void HAL_GPIO_EXTI_Callback(uint16_t GPIO_Pin)
{
  switch (GPIO_Pin)
  {
    case GPIO_PIN_1:
    {    
      if((!DMA_Started) && (current_lr_counter >= LR_COUNT_START)){
        HAL_I2SEx_TransmitReceive_DMA(&hi2s3, (uint16_t*)&send_buff[0], rcv_buff, SEND_BUFF_SZ/2);
        HAL_I2S_Receive_DMA(&hi2s2, (uint16_t*)&adc_buff[0], SEND_BUFF_SZ/2);

        DMA_Started = 0x1;
        current_lr_counter = 0;

        if(!led_on){
          HAL_GPIO_WritePin(LED_PIN_GPIO_Port, LED_PIN_Pin, GPIO_PIN_RESET);
          led_on = 0x1;
        }

      }

      if(DMA_Started){
        tm_timeout = 0;
        break;
      }

      current_lr_counter++;
      break;
    }
    case GPIO_PIN_0:
    {
      led_on = (led_on ? 0 : 1 );
      HAL_GPIO_WritePin(LED_PIN_GPIO_Port, LED_PIN_Pin, led_on ?  GPIO_PIN_RESET : GPIO_PIN_SET);
      __NOP();
    }
    default:{
      __NOP();
      break;
    }
  }
}

void HAL_I2S_RxHalfCpltCallback(I2S_HandleTypeDef* hi2s){
  if(hi2s == &hi2s2){
    memcpy((uint8_t*)&send_buff[0], (uint8_t*)&adc_buff[0], sizeof(send_buff[0])*SEND_BUFF_SZ/2);
  }
}

void HAL_I2S_RxCpltCallback(I2S_HandleTypeDef* hi2s){
  if(hi2s == &hi2s2){
    memcpy((uint8_t*)&send_buff[SEND_BUFF_SZ/2], (uint8_t*)&adc_buff[SEND_BUFF_SZ/2], sizeof(send_buff[0])*SEND_BUFF_SZ/2);
  }
}

/* USER CODE END 4 */
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


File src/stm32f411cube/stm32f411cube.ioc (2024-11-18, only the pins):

Mcu.UserName=STM32F411CEUx
PA0-WKUP.GPIO_Label=BUTTON_KEY
PA0-WKUP.Signal=GPXTI0
PA1.Signal=GPXTI1
PA10.Signal=SPI5_MOSI
PA11.Signal=S_TIM1_CH4
PA12.Signal=SPI5_MISO
PA13.Signal=SYS_JTMS-SWDIO
PA14.Signal=SYS_JTCK-SWCLK
PA15.GPIO_Label=PCM0_SYNC
PA15.Signal=I2S3_WS
PA2.GPIO_Label=CONSOLE_TX
PA2.Signal=USART2_TX
PA3.GPIO_Label=CONSOLE_RX
PA3.Signal=USART2_RX
PA4.GPIO_Label=I2S1_LRCK
PA4.Signal=I2S1_WS
PA5.GPIO_Label=I2S1_BCK
PA5.Signal=I2S1_CK
PA6.GPIO_Label=I2S2_SCK
PA6.Signal=I2S2_MCK
PA7.GPIO_Label=I2S1_DATA_OUT
PA7.Signal=I2S1_SD
PA8.GPIO_Label=ST7735_BL
PA8.Signal=GPIO_Output
PA9.GPIO_Label=SPI5_CS2
PA9.Signal=GPIO_Output
PB0.Signal=SPI5_SCK
PB1.GPIO_Label=SPI5_CS1
PB1.Signal=GPIO_Output
PB10.GPIO_Label=ST7735_CS
PB10.Signal=GPIO_Output
PB12.GPIO_Label=I2S2_LRCK
PB12.Signal=I2S2_WS
PB13.GPIO_Label=I2S2_BCK
PB13.Signal=I2S2_CK
PB14.GPIO_Label=ST7735_DC
PB14.Signal=GPIO_Output
PB15.GPIO_Label=I2S2_DATA_IN
PB15.Signal=I2S2_SD
PB2.GPIO_Label=ST7735_RES
PB2.Signal=GPIO_Output
PB3.GPIO_Label=PCM0_CLK
PB3.Signal=I2S3_CK
PB4.GPIO_Label=PCM0_OUT
PB4.Signal=I2S3_ext_SD
PB5.GPIO_Label=PCM0_INP
PB5.Signal=I2S3_SD
PB6.Signal=I2C1_SCL
PB7.Signal=I2C1_SDA
PB8.GPIO_Label=SPI5_CS3
PB8.Signal=GPIO_Output
PC13-ANTI_TAMP.GPIO_Label=LED_PIN
PC13-ANTI_TAMP.Signal=GPIO_Output

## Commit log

2024-10-13 PCB project
    [2floor_for_orange_pi.kicad_pcb, 2floor_for_orange_pi.kicad_sch]
2024-10-14 completed 1st tracing
    [2floor_for_orange_pi.kicad_pcb, 2floor_for_orange_pi.kicad_sch]
2024-10-19 sended to print
    [2floor_for_orange_pi.kicad_pcb]
2024-11-08 dded photos of recceived PCB<F2>
2024-11-09 added sources files for board (overlay + kernel)
2024-11-18 add SPI-CS1 overlay
2024-12-20 First version of firmware for f411
    [2floor_for_orange_pi-B_Courtyard.gbr, 2floor_for_orange_pi-B_Cu.gbl, 2floor_for_orange_pi-B_Fab.gbr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]

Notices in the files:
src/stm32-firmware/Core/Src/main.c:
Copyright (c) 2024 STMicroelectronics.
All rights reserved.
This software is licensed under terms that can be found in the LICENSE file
